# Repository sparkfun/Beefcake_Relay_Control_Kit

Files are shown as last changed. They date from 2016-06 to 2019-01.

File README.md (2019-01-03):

Beefcake Relay Control Kit
==========================

[Beefcake Relay Control Kit  
*Beefcake Relay Control Kit (KIT-13815)*](https://www.sparkfun.com/products/13815)

The Beefcake Relay Control Kit contains all the parts you need to get your high-power load under control.

Repository Contents
-------------------

* **/Hardware** - Eagle design files (Schematic and Board)

Documentation
--------------
* **[Hookup Guide](https://learn.sparkfun.com/tutorials/beefcake-relay-control-hookup-guide)** - Basic hookup guide for the Beefcake Relay Control Kit.
* **[SparkFun Fritzing repo](https://github.com/sparkfun/Fritzing_Parts)** - Fritzing diagrams for SparkFun products.

Product Versions
----------------
* [KIT-13815](https://www.sparkfun.com/products/13815) - Beefcake Relay Control Kit

Version History
---------------
* [v1.6](https://github.com/sparkfun/Beefcake_Relay_Control_Kit/tree/v1.6) - SPST version
* [v2.0](https://github.com/sparkfun/Beefcake_Relay_Control_Kit/tree/v2.0) - SPDT version

License Information
-------------------

This product is _**open source**_! 

Please review the LICENSE.md file for license information. 

If you have any questions or concerns on licensing, please contact techsupport@sparkfun.com.

Distributed as-is; no warranty is given.

- Your friends at SparkFun.

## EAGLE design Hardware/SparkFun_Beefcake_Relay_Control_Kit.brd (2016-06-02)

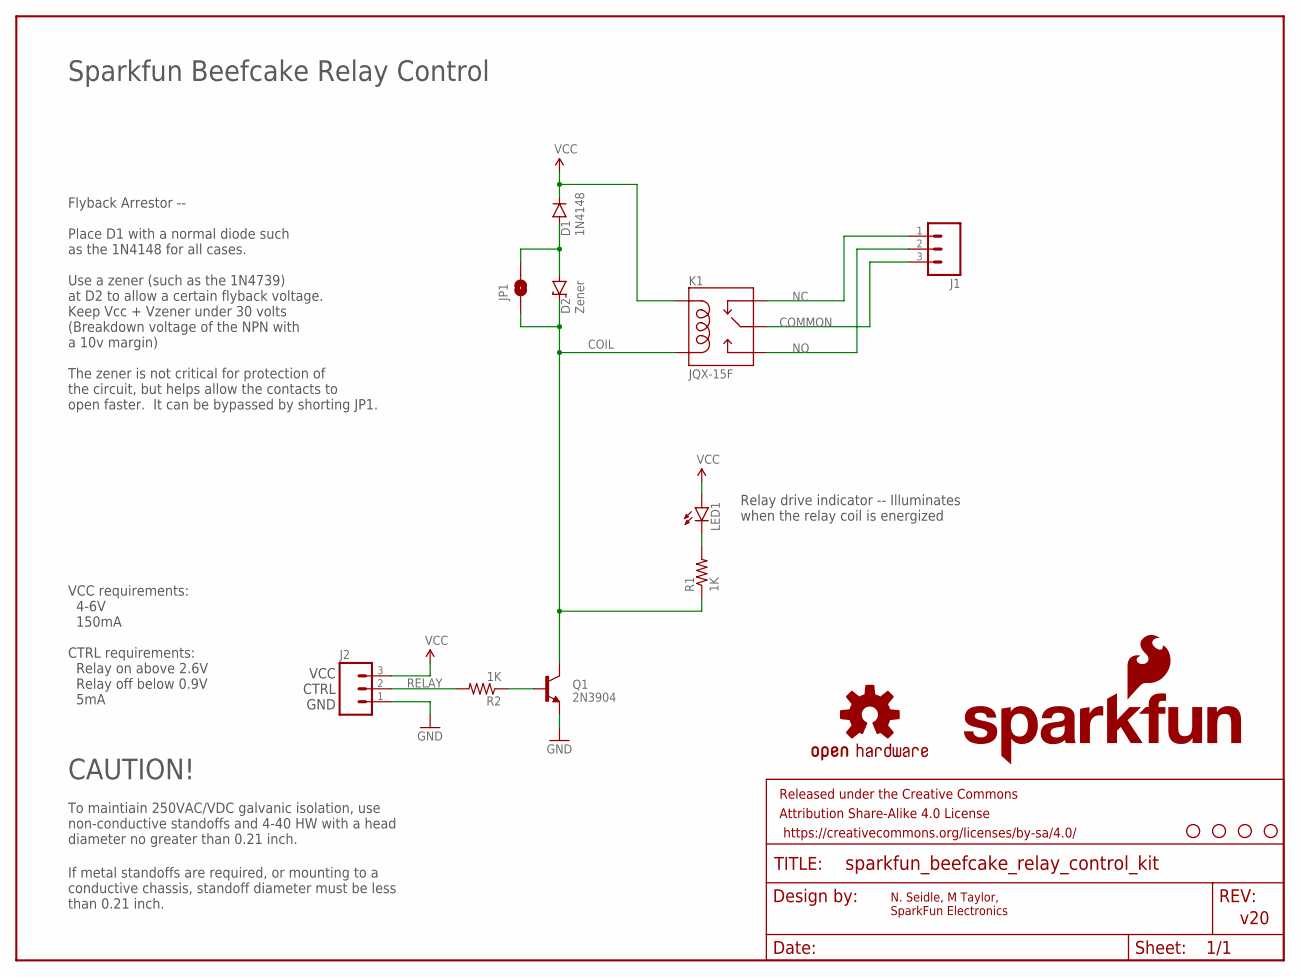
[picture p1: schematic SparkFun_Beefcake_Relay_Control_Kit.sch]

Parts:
D1: 1N4148; DIODE-1N4148-KIT
D2: Zener; DIODE-1N4148-KIT
FRAME2: FRAME-LETTER; CREATIVE_COMMONS
J1: M03-SCREW-5MM; SCREWTERMINAL-5MM-3
J2: M03SCREW; SCREWTERMINAL-3.5MM-3
JP1: JUMPER-PAD-2-NOYES_SILK; PAD-JUMPER-2-NO_YES_SILK
K1: JQX-15F; RELAY-T90
LED1: LED5MM-KIT
LOGO1: SFE_LOGO_NAME_FLAME.1_INCH; SFE_LOGO_NAME_FLAME_.1
Q1: 2N3904; TO-92-EZ
R1, R2: 1K; AXIAL-0.3EZ
U$3, U$4, U$5, U$7: STAND-OFF
U$12: OSHW-LOGOS; OSHW-LOGO-S

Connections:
COIL: D2.C, JP1.1, K1.COIL2, Q1.3 (C), R1.P$1 (1)
COMMON: J1.3, K1.MAIN
DIODENODE: D1.A, D2.A, JP1.2
GND: J2.1, Q1.1 (E)
unnamed: Q1.2 (B), R2.P$1 (1)
unnamed: LED1.K (C), R1.P$2 (2)
NC: J1.1, K1.NC
NO: J1.2, K1.NO
RELAY: J2.2, R2.P$2 (2)
VCC: D1.C, J2.3, K1.COIL1, LED1.A

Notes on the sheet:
N. Seidle, M Taylor, SparkFun Electronics
v20
Relay drive indicator -- Illuminates when the relay coil is energized
Flyback Arrestor -- Place D1 with a normal diode such as the 1N4148 for all cases. Use a zener (such as the 1N4739) at D2 to allow a certain flyback voltage. Keep Vcc + Vzener under 30 volts (Breakdown voltage of the NPN with a 10v margin) The zener is not critical for protection of the circuit, bu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
To maintiain 250VAC/VDC galvanic isolation, use non-conductive standoffs and 4-40 HW with a head diameter no greater than 0.21 inch.
CAUTION!
If metal standoffs are required, or mounting to a conductive chassis, standoff diameter must be less than 0.21 inch.
VCC requirements: 4-6V 150mA CTRL requirements: Relay on above 2.6V Relay off below 0.9V 5mA
VCC CTRL GND
Sparkfun Beefcake Relay Control

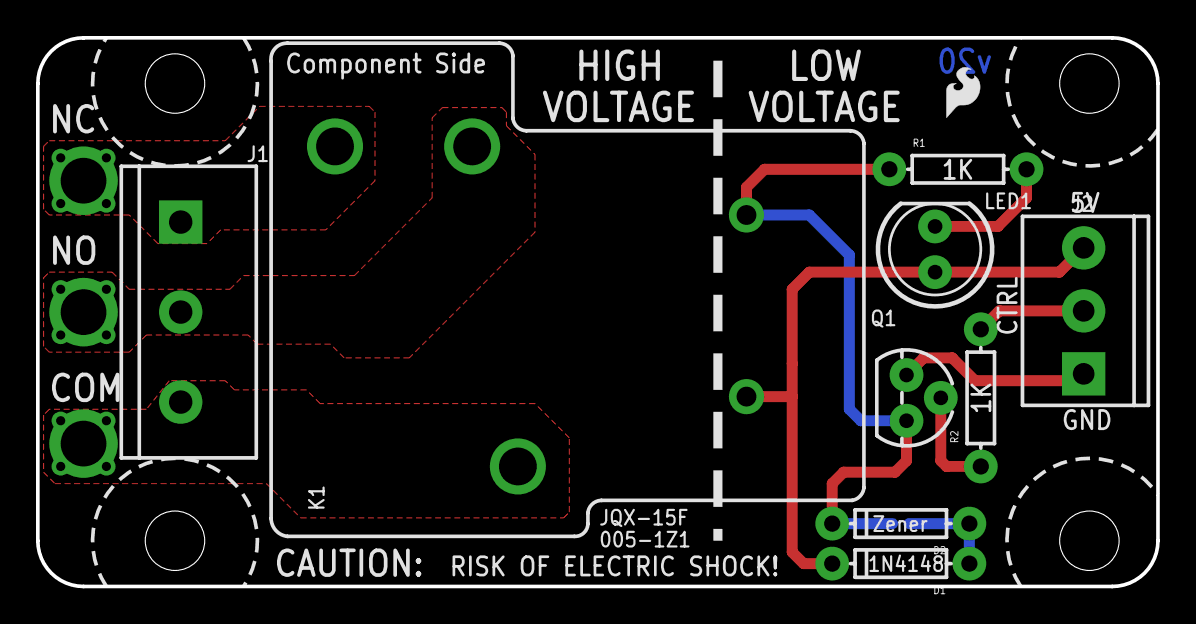
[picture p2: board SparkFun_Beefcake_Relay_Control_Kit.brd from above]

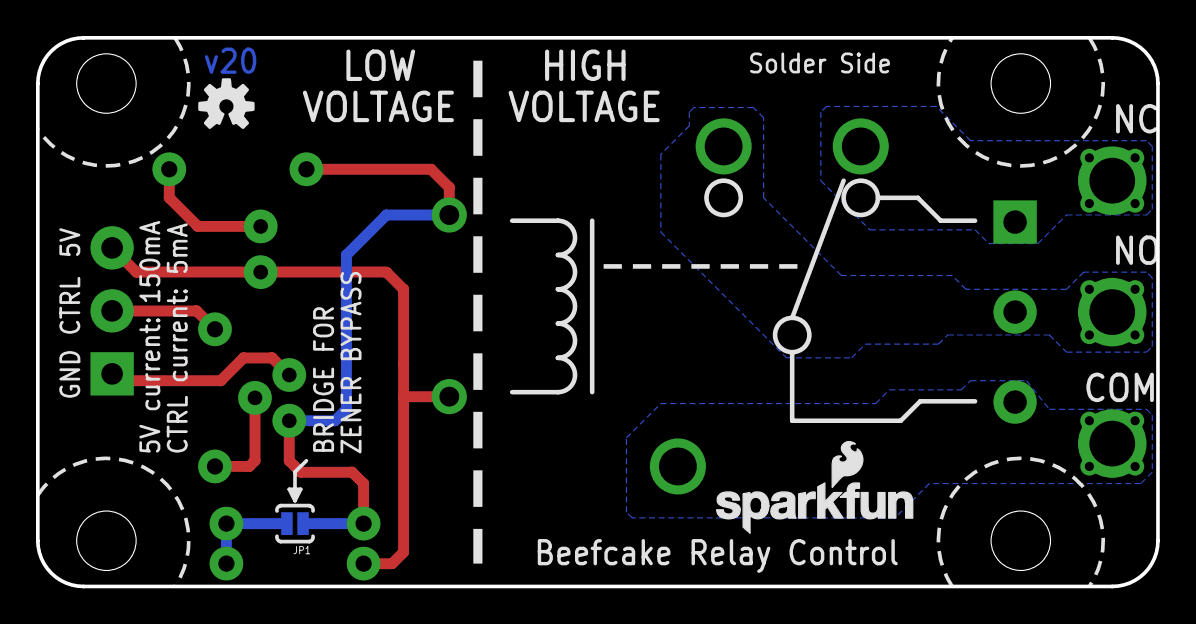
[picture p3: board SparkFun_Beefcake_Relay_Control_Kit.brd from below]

Board: 2 copper layers, 62.2 x 30.5 mm, 18 parts (3 on the bottom side), 10 nets.

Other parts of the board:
U$11: SFE-LOGO-FLAME

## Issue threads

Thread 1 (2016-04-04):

Engineering Review feedback

ToniCorinne, 2016-04-04:
-Add known current for control line to board silk
-Add notation about 2oz copper to bug when cleared for reds,
-Bump up trace widths on low voltage side
-Bump up size of "CAUTION" silk
-Consider rounding corners (curve starts 20mil from corner)

marshalltaylorSFE, 2016-04-05:
Done

Closed 2016-04-05.

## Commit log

2014-01-31 initial v17 eagle files
    -gitignore and readme update.
    -updated frame
    -added version to bottom copper
    [Beefcake_Relay_Control_Kit.brd, Beefcake_Relay_Control_Kit.sch]
2015-01-19 Updating file names
    [SparkFun_Beefcake_Relay_Control_Kit.brd, SparkFun_Beefcake_Relay_Control_Kit.sch]
2015-01-19 Update to current board files
    [SparkFun_Beefcake_Relay_Control_Kit.brd, SparkFun_Beefcake_Relay_Control_Kit.sch, SparkFun_RelayBoard-Large-v16.brd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]
2016-01-29 Design ready for proto 1 review
    [SparkFun_Beefcake_Relay_Control_Kit.brd, SparkFun_Beefcake_Relay_Control_Kit.sch]
2016-02-01 Running through review changes
    [SparkFun_Beefcake_Relay_Control_Kit.brd, SparkFun_Beefcake_Relay_Control_Kit.sch]
2016-02-01 Ready for QC's review
    [SparkFun_Beefcake_Relay_Control_Kit.brd, SparkFun_Beefcake_Relay_Control_Kit.sch]
2016-02-03 updated bom
    [SparkFun_Beefcake_Relay_Control_Kit.brd, SparkFun_Beefcake_Relay_Control_Kit.sch]
2016-04-04 updated silk for redboard review
    [SparkFun_Beefcake_Relay_Control_Kit.brd, SparkFun_Beefcake_Relay_Control_Kit.sch]
2016-04-05 Finished for reds review, implemented changes
    [SparkFun_Beefcake_Relay_Control_Kit.brd, SparkFun_Beefcake_Relay_Control_Kit.sch]
2016-04-05 prepping for QC action
    [Board_Design_Checklist_BeefCake Relay Control_.xls, SparkFun_Beefcake_Relay_Control_Kit.brd, SparkFun_Beefcake_Relay_Control_Kit.sch]
2016-04-07 Resolved github issues
    [Board_Design_Checklist_BeefCake Relay Control_.xls, SparkFun_Beefcake_Relay_Control_Kit.brd, SparkFun_Beefcake_Relay_Control_Kit.sch]
2016-04-07 updated designators
    [SparkFun_Beefcake_Relay_Control_Kit.brd, SparkFun_Beefcake_Relay_Control_Kit.sch]
2016-06-02 Pointed pictures and links to new product listing, preparing for merge, fixed typo in schematic text
    [SparkFun_Beefcake_Relay_Control_Kit.sch]

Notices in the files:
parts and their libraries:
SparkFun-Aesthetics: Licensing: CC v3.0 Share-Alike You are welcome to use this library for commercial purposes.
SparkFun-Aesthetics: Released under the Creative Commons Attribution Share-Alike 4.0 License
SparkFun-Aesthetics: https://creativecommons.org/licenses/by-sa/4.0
